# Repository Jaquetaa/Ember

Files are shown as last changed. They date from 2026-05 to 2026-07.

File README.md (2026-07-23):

<p align="center">
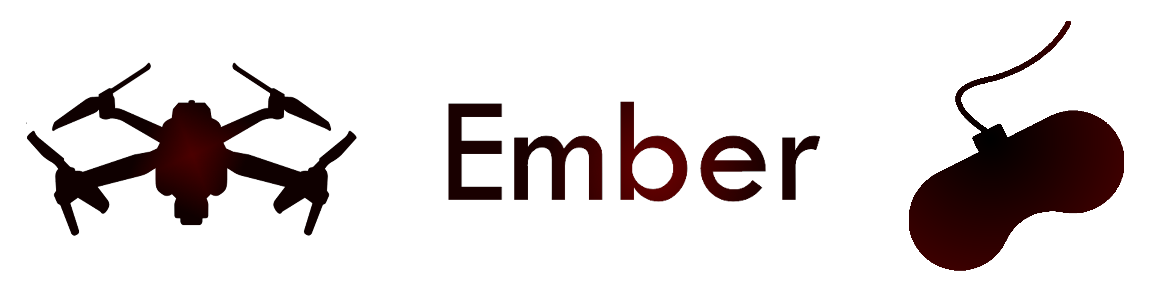
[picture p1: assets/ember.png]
Ember
  
</p>

<h3 align="center">Projeto Ember | Prova de Aptidão Profissional</h3>

---

> [!CAUTION]
> **Esta branch é apenas usada para a documentação importante do projeto, lê mais abaixo.**

---

## Introdução

O Ember é um sistema de deteção de incêndios florestais, composto por um drone e um comando que trabalham em conjunto para identificar focos de incêndio o mais cedo possível.

Este projeto representa o culminar de tudo o que aprendemos ao longo do nosso curso no secundário.

> [!WARNING]
> **Este repositório foi disponibilizado por conveniência própria e como forma de contribuir para a comunidade.**
>
> **Nós não nos responsabilizamos por:**
>
> - Plágio ou uso indevido deste conteúdo em trabalhos de terceiros,
> - Qualquer _misuse_ do projeto, incluindo aplicações fora do âmbito para o qual foi concebido,
> - Danos, perdas ou prejuízos resultantes do uso do hardware, software ou informação aqui presentes,
> - Falhas de detecção ou falsos alarmes.
> 
> Isto é um projeto académico e um protótipo, não certificado nem testado para uso em situações reais de emergência.
> 
> **A responsabilidade pela utilização deste código é de quem o usa, não nossa.**
---

## Sobre o Projeto

Este projeto é uma construção de um drone com a adição de um comando para a nossa Prova de Aptidão Profissional (PAP), feita em Arduino (C++) com ESP's e entre outros tipos de hardware, como sensores.

**O objetivo do drone é a detecção e prevenção de incêndios, e o comando vai pilotar o drone.**

Este projeto foi feito utilizando o editor de código [VSCode](https://code.visualstudio.com/) com a extensão [PlatformIO](https://platformio.org/install/ide?install=vscode).

### No final, este projeto e apresentação foi avaliada com uma classificação máxima de 20/20 para ambos.

---

## Como Montar?

**Este projeto usa dois microcontroladores, um para o [drone](https://github.com/Jaquetaa/Ember/tree/drone) e um para o [comando](https://github.com/Jaquetaa/Ember/tree/comando),**

Todos os materiais necessários para recriar este projeto ([listas de componentes](https://github.com/Jaquetaa/Ember/blob/arquivos/PAP%20Ember.xlsx), etc.) estão aqui.

**Nós não chegamos a usar as placas de circuito impresso, mas os ficheiros (e pinos) correspondem corretamente, basta encomendar e montar.**

---

## Apresentação e Relatório da PAP

Não vamos incluir apresentações/relatórios do projeto por motivos de privacidade e prevenção de plágio.

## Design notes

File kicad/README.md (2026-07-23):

<p align="center">
  Ember
</p>

<h3 align="center">Estas são as placas PCB que fizemos para o nosso projeto,</h3>

<h3 align="center">Não foram usadas na versão final, mas são funcionais.</h3>

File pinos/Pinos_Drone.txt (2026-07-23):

spi_partilhado
sck 17
miso 18
mosi 7

nrf_controlo
vcc
gnd
sck 17
miso 18
mosi 7
ce 13
csn 12

nrf_termico
vcc
gnd
sck 17
miso 18
mosi 7
ce 2
csn 40

escs
vcc
gnd
esc1 19
esc2 14
esc3 1
esc4 4

sensores
vcc
gnd
chama 8
mq7_gas 20

botoes
vcc
gnd
calibracao 3
skip_preheat 39

cam
vcc
gnd
sda 41
scl 42

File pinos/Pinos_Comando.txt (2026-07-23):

spi_partilhado
sck 48
miso 16
mosi 47

nrf_controlo
vcc
gnd
sck 48
miso 16
mosi 47
ce 14
csn 13

nrf_termico
vcc
gnd
sck 48
miso 16
mosi 47
ce 12
csn 11

ecra_tft
vcc
gnd
sck 48
miso 16
mosi 47
cs 41
dc 21
rst 42
bl 45

joystick_esquerdo
vcc
gnd
y 4
x 5

joystick_direito
vcc
gnd
y 2
x 1

botoes
vcc
gnd
arm 17
stop 18

alarme
vcc
gnd
buzzer 10
led_gas 3
led_chama 20

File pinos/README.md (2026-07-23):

<p align="center">
  Ember
</p>

<h3 align="center">Estes são os pinos (GPIO's) montados no nosso projeto final.</h3>

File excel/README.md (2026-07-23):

<p align="center">
  Ember
</p>

<h3 align="center">Esta é a lista de componentes usados, entre outros.</h3>

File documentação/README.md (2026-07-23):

<p align="center">
  Ember
</p>

<h3 align="center">Aqui está documentação útil sobre o projeto.</h3>

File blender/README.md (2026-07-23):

<p align="center">
  Ember
</p>

<h3 align="center">Aqui fica o ficheiro do <a href="https://www.blender.org/download/">Blender</a> da modelagem do comando.</h3>

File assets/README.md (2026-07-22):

<p align="center">
  Ember
</p>

<h3 align="center">Esta pasta só serve para guardarmos imagens relacionadas com o projeto.</h3>

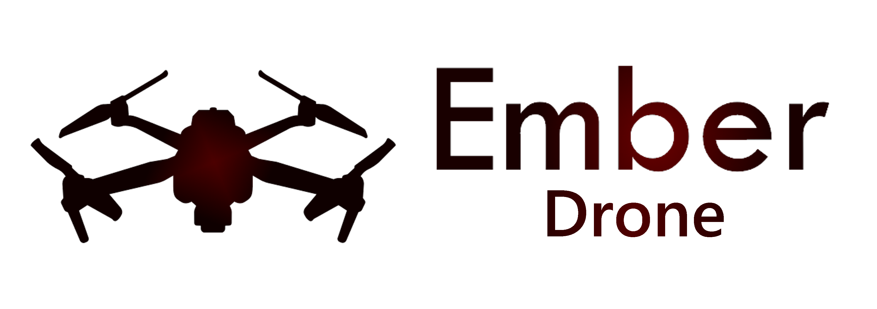
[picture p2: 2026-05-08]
assets/drone/ember drone indicador.png

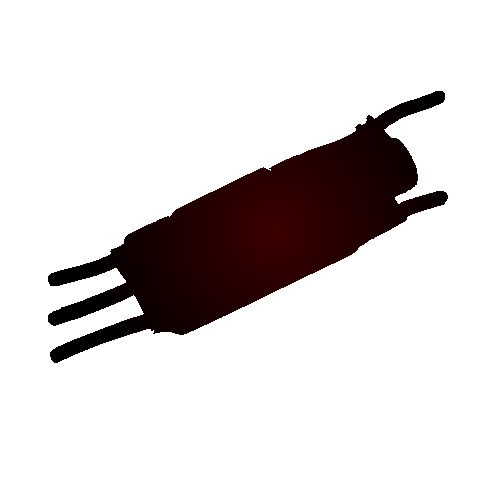
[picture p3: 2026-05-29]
assets/diagrama/esc.png

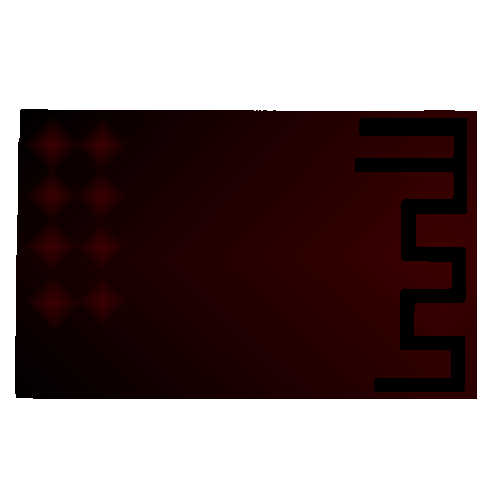
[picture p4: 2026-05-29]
assets/diagrama/transceptores.png

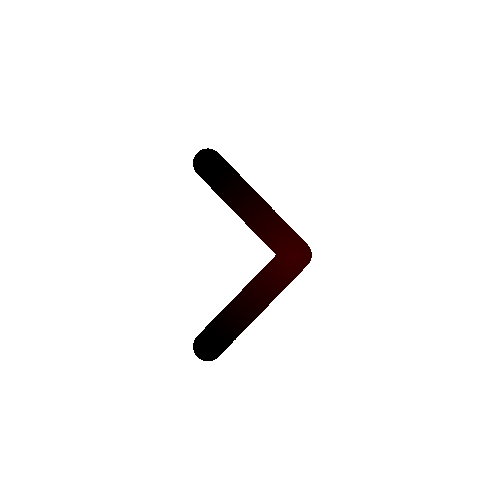
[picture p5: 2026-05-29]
assets/diagrama/next.png

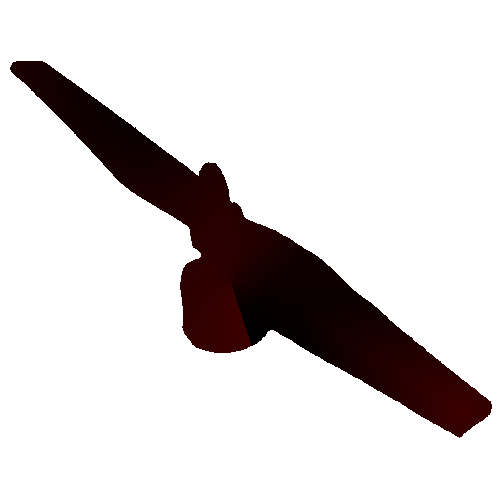
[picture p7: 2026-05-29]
assets/diagrama/motor.png

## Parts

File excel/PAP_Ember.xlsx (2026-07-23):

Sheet: Material
 |  |  |  |  |  |  |  |  | Mauser
 |  |  |  |  |  |  |  |  | Digikey
DRONE |  |  |  |  |  | CONTAS |  |  | Mauser
NOME | MODELO/REF | QNT P/ EQUIP. | PREÇO | COMPRADO P. | LOJA / LUGAR |  |  |  | Digikey
Microcontrolador | ESP32-S3 WROOM-1 | 1 | €10.37 | TIAGO | Mauser | DRONE |  |  | Mauser
Câmara Térmica | 55º MLX90640 | 1 | €0.00 | OUTRO | Digikey | QNT EQUIP. | FREQ. LOJA / LUGAR | TOTAL | HobbyKing
Sensor de Gás | MQ-7 | 1 | €0.00 | OUTRO | Mauser | 21 | Mauser | €266.86 | Amazon
Sensor de Chama | YG1006 | 1 | €0.00 | OUTRO | Digikey |  |  |  | Amazon
Tranceptores | Whadda WPI322 | 2 | €0.00 | OUTRO | Mauser | COMANDO |  |  | Mauser
ESC | 20A | 4 | €19.11 | TIAGO | HobbyKing | QNT EQUIP. | FREQ. LOJA / LUGAR | TOTAL | Amazon
Motor sem Escovas | A2212 1000KV | 4 | €18.99 | TIAGO | Amazon | 16 | Mauser | €60.20 | Amazon
Bateria | LiPo 2200MAH 11.1V (3S) 130C | 1 | €28.96 | TIAGO | Amazon |  |  |  | Casa
Breadboard | Qualquer, Grande | 1 | $8.84 | TIAGO | Mauser | DRONE + COMANDO |  |  | Mauser
Estrutura | F450 Quadcopter | 1 | €23.75 | TIAGO | Amazon | QNT EQUIP. | FREQ. LOJA / LUGAR | TOTAL | Amazon
Conector XT60 | Pacote M / F | 2 | €21.27 | TIAGO | Amazon | 37 | Mauser | €327.06 | Amazon
Condensador | 10UF 16V | 2 | €0.00 | OUTRO | Casa |  |  |  | Mauser
 |  |  |  |  |  | DRONE + COMANDO + GERAL / OUTROS |  |  | Escola
COMANDO |  |  |  |  |  | QNT EQUIP. | FREQ. LOJA / LUGAR | TOTAL | Escola
NOME | MODELO/REF | QNT P/ EQUIP. | PREÇO |  | LOJA / LUGAR | 58 | Mauser | €482.43 | Escola
Microcontrolador | ESP32-S3 WROOM-1 | 1 | €10.37 | TIAGO | Mauser |  |  |  | Mauser
Ecrã | LAFVIN TFT LCD 4.0" | 1 | €25.34 | TIAGO | Amazon | MATERIAL NÃO USADO |  |  | Amazon
Pilha | 9V | 1 | €8.34 | TIAGO | Amazon | QNT EQUIP. | FREQ. LOJA / LUGAR | TOTAL | Mauser
Joystick | KS0008 | 2 | €0.00 | OUTRO | Mauser | 2 | Mauser | €25.00 | Casa
Botão | Genérico, Botão Tátil | 2 | €0.00 | OUTRO | Escola |  |  |  | 0
LED | Genérico, Vermelho e Amarelo | 2 | €0.00 | OUTRO | Escola | Isto foi o que nós gastamos no projeto, não inclui o que obtemos gratuitamente.
Buzzer | Piezo Ativo | 1 | €0.00 | OUTRO | Escola | Se tiveres a fazer plágio na tua PAP, espero que isto te assuste o suficiente.
Transceptor | Whadda WPI322 | 2 | €0.00 | OUTRO | Mauser |  |  |  | Amazon
Conversor Buck | LM2596 | 1 | €7.31 | TIAGO | Amazon | Isto não inclui muitas das peças que nós queimamos/não usamos ou que ficaram extra, senão daria 929.40€. |  |  | Amazon
Breadboard | Qualquer, Grande | 1 | $8.84 | TIAGO | Mauser |  |  |  | Leroy Merlin
Condensador | 10UF 16V | 2 | €0.00 | OUTRO | Casa |  |  |  | Mauser
 |  |  |  |  |  |  |  |  | Várias
GERAL / OUTROS |  |  |  |  |  |  |  |  | Curto Circuito
NOME | MODELO/REF | QNT P/ EQUIP. | PREÇO |  | LOJA / LUGAR |  |  |  | Farmácia
Carregador LiPo | HAISITO HB6 | 1 | €45.99 | TIAGO | Amazon |  |  |  | Leroy Merlin
LiPo Buzzer | YUNIQUE GREEN-CLEAN-POWER | 1 | €21.28 | TIAGO | Amazon |  |  |  | 0
Parafusos | Vários | 2 | €2.80 | TIAGO | Leroy Merlin |  |  |  | 0
Pinos | Conjunto 40 (F) | 4 | €0.73 | TIAGO | Mauser |  |  |  | 0
Jumpers | Conjunto (MM, MF, FF) | 8 | €3.50 | AMBOS | Várias
Ácido | Cloreto Férrico | 1 | €35.90 | GONÇALO | Curto Circuito |  |  |  | 0
Álcool | Isopropílico | 1 | €0.00 | TIAGO | Farmácia |  |  |  | 0
Chaves de Ferramentas | Conjunto | 1 | €0.00 | TIAGO | Leroy Merlin |  |  |  | 0
Lixa | Água (Grau 200) | 1 | €0.00 | OUTRO | Casa
Lata Spray Tinta | Branca para PVC | 1 | €8.00 | TIAGO | Leroy Merlin
Impressora 3D | Elegoo Neptune 4 |  | €0.00 | OUTRO | Escola
Filamento | PLA 1.75MM 1KG (LARANJA) | 1 | €0.00 | OUTRO | Escola
Velcro | Adesivos de Dupla Face | 1 | €7.68 | TIAGO | Amazon
Fita Isolante | Rolo Preto | 1 | €0.00 | OUTRO | Casa |  |  |  | 0
 |  |  |  |  |  |  |  |  | 0
NÃO USADOS |  |  |  |  |  |  |  |  | 0
Placa PCB | Dupla Camada, Tratamento UV | 2 | €25.00 | GONÇALO | Mauser |  |  |  | 0
 |  |  |  |  |  |  |  |  | 0
Apesar de não termos usado no projeto final, está disponivel um circuito para placas de circuito impresso que servem para a placa referida acima,
Funciona da mesma forma, com os mesmos pinos.
Nota:
O motor do drone pode não ser força o suficiente para voar (depedendo do peso), se quiseres podes dar upgrade para um motor A2216 com ESC's de 40A caso adiciones algo mais no drone.
Se fores fazer este upgrade, muda os valores de throttle no código principal da parte do drone.

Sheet: Planeamento
Calendário (Expectativa) |  |  | Timeline | Calendário (Realidade) |  |  | Timeline
Etapas | Tarefa | Mês |  | Etapas | Tarefa | Mês
1 | Planeamento de Ideias | 2025-09-01 | Passado | 1 | Planeamento de Ideias | 2025-09-01 | Passado
2 | Fazer Checklist dos Materiais Pesquisa do Trabalho | 2025-10-01 |  | 2 | Fazer Checklist dos Materiais Pesquisa do Trabalho | 2025-10-01
3 | Encomendar Materiais Fazer Relatório/Apresentação da Pre-PAP Verificar Compatibilidade dos Materiais | 2025-11-01 | Presente | 3 | Encomendar Materiais Fazer Apresentação da Pre-PAP Verificar Compatibilidade dos Materiais | 2025-11-01
4 | Testar Materiais Encomendar Materiais Restantes Estudo em Programação C++ | 2025-12-01 | Futuro | 4 | Testar Materiais Encomendar Materiais Restantes Estudo em Programação C++ | 2025-12-01
5 | Iniciar as Montagens (Protótipo) Estudo em Programação C++ | 2026-01-01 |  | 5 | Testar Materiais Estudo em Programação C++ | 2026-01-01
6 | Iniciar a Montagem Estudo em Programação C++ | 2026-02-01 |  | 6 | Testar Materiais Estudo em Programação C++ | 2026-02-01
7 | Montagem | 2026-03-01 |  | 7 | Montagem do Protótipo Design da Placa PCB | 2026-03-01
8 | Montagem Realização de um Show do Drone Fazer o Relatório/Apresentação Final | 2026-04-01 |  | 8 | Montagem do Protótipo Modelagem em Blender e Design PCB | 2026-04-01
 |  |  |  | 9 | Fazer a Pré-Apresentação Final Treinar Apresentação Modelagem em Blender e Design PCB | 2026-05-01 | Presente
9 | Fazer o Relatório/Apresentação Final Treinar Apresentação | 2026-05-01
10 | Treinar Apresentação | 2026-06-01 |  | 10 | Terminar o Trabalho | 2026-06-01 | Futuro
 |  |  | CALENDÁRIO FEITO EM NOVEMBRO DE 2025 |  |  |  | CALENDÁRIO FEITO EM ABRIL DE 2026
Isto foi o nosso planeamento de como iria decorrer o nosso projeto, com uma expectativa vs realidade.
Se tiveres a recriar este projeto, podes ignorar esta sheet.

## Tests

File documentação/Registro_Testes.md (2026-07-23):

# Ember — Registo de Testes

## Alcance do rádio
Testado visualmente a ~30m, com ligação estável.
Segundo o datasheet do NRF24L01: 20-50m com obstáculos, até 100m em ar livre.

## Autonomia da bateria
10 minutos com throttle constante. Considerado bom para este tipo de drone.

## Precisão da câmara térmica
Funciona bem, destaca claramente fontes de calor. Alcance eficaz de 5-10 metros.
Sendo uma prova de conceito, não foi otimizada para alcance máximo.

## Calibração
Por motivos de segurança, correr o código de calibração (`(drone)/older/CALIBRAR.ino`) com as hélices retiradas dos motores (recomendo), ou usar a built-in calibração (não recomendo)

## Peso
Atualmente 1.1kg, levanta voo (tens que levantar o drone com CUIDADO por segurança)

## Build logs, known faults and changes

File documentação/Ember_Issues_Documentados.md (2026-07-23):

# Ember — Issues Cruciais
Caso fores recriar este projeto, tem aqui problemas (mais importantes) e soluções que tivemos ao longo do projeto:

---

## Hardware Bugs

### #4 — Problemas Prévios
**Problema:** Alimentação incorreta dos motores brushless.
**Solução:** Não alimentar o 3V do ESC.

### #6 — Reviver a bateria
**Problema:** Bateria LiPo queimada quimicamente por nunca ter sido posta a carregar corretamente.
**Solução:** Não deixes a bateria descarregar! Usa um lipo buzzer (recomendado) ou programa tu próprio um sistema de detecção de bateria fraca.

### #11 — Delay na conexão
**Problema:** Ligação com atraso elevado entre comando e drone.
**Solução:** Causa apontada para fios mal ligados na breadboard e clips desgastados/largos; resolvido indiretamente com a troca de breadboards (#16).

### #16 — Trocar as breadboards
**Problema:** Má conexão dos pinos na breadboard.
**Solução:** Substituição das breadboards para umas mais fixas e melhores, correção que resolveu praticamente todos os problemas de comunicação.

### #38 — Comunicação só funciona apenas numa porta USB (sem bateria ligada)
**Problema:** Alimentação insuficiente nalgumas portas USB fazia os transceptores falhar.
**Solução:** Mudança da porta USB, literalmente só isso..

### #38 — Verificar que todos os motores estão a girar na direção correta
**Problema:** Fazer os motores girarem para dentro
**Solução:** Trocar os cabos do motor com o ESC.

### #47 — Hélice direita e esquerda
**Problema:** As hélices têm direções específicas!
**Solução:** Colocar as hélices certas no lugar correto, existem estilo "esquerdas e direitas", não estou a falar de girarem na direção correta, isso é outra coisa.

---

## Software Bugs

### #1 — Sincronismo das hélices
**Problema:** Ao ligar o sistema, as hélices não arrancavam em sincronismo.
**Solução:** Tens que calibrar o drone! (Retira hélice do motor antes para evitar danos)

---

## Montagem

### #32 — Encontrar o ponto de hover
**Problema:** Necessário o drone montado por completo (peso final) para calibrar o ponto de hover.
**Solução:** Varia com a hélice, bateria, motor... Ajusta o valor em Gonçalo_Ember.ino (Drone)

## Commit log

2026-03-10 Led Receptor
    Código representativo, não é o final nem aquele que vai ser a biblioteca do receptor
2026-07-22 aralab
    fica melhor contraste para dark mode
2026-07-23 update PAP Ember.xlsx
    [PAP Ember.xlsx]
2026-07-23 excel (organizado)
    [PAP_Ember.xlsx]
2026-07-23 organização de arquivos/docs
    fica melhor assim (de acordo comigo)
    [Ember_Comando.kicad_pcb, Ember_Drone.kicad_pcb, PAP_Ember.xlsx]
2026-07-23 remover uns ficheiros extra
    [PAP Ember.xlsx, PAP_Ember.xlsx]
2026-07-23 kicad info
2026-07-23 upd excel
    [PAP_Ember.xlsx]
2026-07-23 excel documentado
    [PAP_Ember.xlsx]
